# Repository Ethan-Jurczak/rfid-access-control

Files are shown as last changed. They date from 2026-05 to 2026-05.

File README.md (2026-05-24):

# rfid-access-control
stm32 based RFID system.
# Specs
- Runs off a STM32f411ret arm microcontroller with a EM4095 for the RFID demodulation and writing modulation.
- Includes a USB-C receptacle for both power and data transfer to the STM32
- Includes a 4 pin connecter for programing with a STlink
- 520 uH coil connected in series accross 4 layers to minimize space while maximising Q
# Schematics
- [RFID-Read-Write-Schematic.pdf](https://github.com/user-attachments/files/28185533/RFID-Read-Write-Schematic.pdf)
RFID-Read-Write-Front
RFID-Read-Write-Back

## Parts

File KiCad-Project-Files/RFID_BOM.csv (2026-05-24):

Reference | Qty | Value | DNP | Exclude from BOM | Exclude from Board | Footprint | Datasheet
AccessLed1,AccessLed2 | 2 | LED |  |  |  | LED_SMD:LED_0603_1608Metric
C1,C2 | 2 | 33 pF |  |  |  | Capacitor_SMD:C_0402_1005Metric
C3,C5,C7,C9,C10,C11,C12,C14,C17,CDEC1 | 10 | 100nF |  |  |  | Capacitor_SMD:C_0402_1005Metric
C4 | 1 | 150nF |  |  |  | Capacitor_SMD:C_0402_1005Metric
C6 | 1 | 1 uF |  |  |  | Capacitor_SMD:C_0402_1005Metric
C8 | 1 | 4.7uF |  |  |  | Capacitor_SMD:C_0603_1608Metric
C13 | 1 | 1uF |  |  |  | Capacitor_SMD:C_0402_1005Metric
C16,C18 | 2 | 10 uF |  |  |  | Capacitor_SMD:C_0805_2012Metric
CDC1,CFCAP1 | 2 | 10nF |  |  |  | Capacitor_SMD:C_0603_1608Metric
CDV1 | 1 | 56pF |  |  |  | Capacitor_SMD:C_0805_2012Metric
CDV2 | 1 | 1.5nF |  |  |  | Capacitor_SMD:C_0805_2012Metric
CRES1 | 1 | 3nF |  |  |  | Capacitor_SMD:C_0603_1608Metric
CTUNE1 | 1 | ?pF |  |  |  | Capacitor_SMD:C_0402_1005Metric
D1 | 1 | PTVS5V0Z1USK |  |  |  | Diode_SMD:Nexperia_DSN1608-2_1.6x0.8mm | https://assets.nexperia.com/documents/data-sheet/PTVS5V0Z1USK.pdf
EM1 | 1 |  |  |  |  | EM4095:SO16
F1 | 1 | MF-MSMF050-2 |  |  |  | Fuse:Fuse_1812_4532Metric
FB1 | 1 | 600 Ohm @ 100mHz |  |  |  | Inductor_SMD:L_0805_2012Metric
J1 | 1 | Conn_01x04_Pin |  |  |  | Connector_JST:JST_EH_B4B-EH-A_1x04_P2.50mm_Vertical
J2 | 1 | USB_C_Receptacle |  |  |  | EM4095:SAMESKY_UJ20-C-H-G-SMT-1-P16-TR | https://www.usb.org/sites/default/files/documents/usb_type-c.zip
LA1 | 1 | 520uH
Q1 | 1 | 2N7002 |  |  |  | Package_TO_SOT_SMD:SOT-23 | https://www.onsemi.com/pub/Collateral/NDS7002A-D.PDF
R1 | 1 | 100 Ohm |  |  |  | Resistor_SMD:R_0402_1005Metric
R2,R8 | 2 | 10k Ohm |  |  |  | Resistor_SMD:R_0603_1608Metric
R3,R4 | 2 | 22 Ohm |  |  |  | Resistor_SMD:R_0402_1005Metric
R5,R6 | 2 | 5.1k Ohm |  |  |  | Resistor_SMD:R_0402_1005Metric
R9 | 1 | 100 Ohm |  |  |  | Resistor_SMD:R_0603_1608Metric
RSER1 | 1 | 33Ohm |  |  |  | Resistor_SMD:R_0402_1005Metric
R_FB1 | 1 | 1M Ohm |  |  |  | Resistor_SMD:R_0402_1005Metric
Status1 | 1 | LED |  |  |  | LED_SMD:LED_0805_2012Metric
SW1,SW2 | 2 | SW_Push |  |  |  | Button_Switch_SMD:SW_Tactile_SPST_NO_Straight_CK_PTS636Sx25SMTRLFS
U1 | 1 | STM32F411RETx |  |  |  | Package_QFP:LQFP-64_10x10mm_P0.5mm | https://www.st.com/resource/en/datasheet/stm32f411re.pdf
U2 | 1 | USBLC6 |  |  |  | Package_TO_SOT_SMD:SOT-23-6 | https://www.st.com/resource/en/datasheet/usblc6-2.pdf
VR1 | 1 | LM1117MPX-3.3_NOPB |  |  |  | Package_TO_SOT_SMD:SOT-223-3_TabPin2
Y1 | 1 | ECS-80-20-5PXDU-TR |  |  |  | EM4095:XTAL_ECS-80-20-5PXDU-TR

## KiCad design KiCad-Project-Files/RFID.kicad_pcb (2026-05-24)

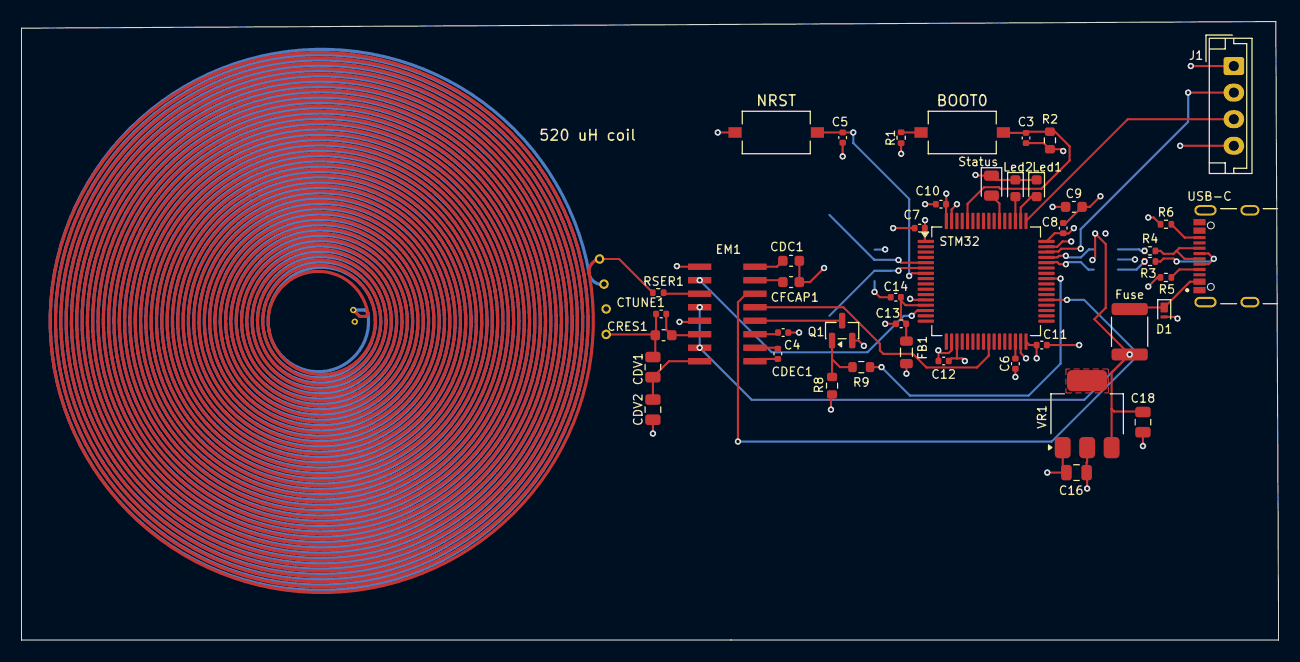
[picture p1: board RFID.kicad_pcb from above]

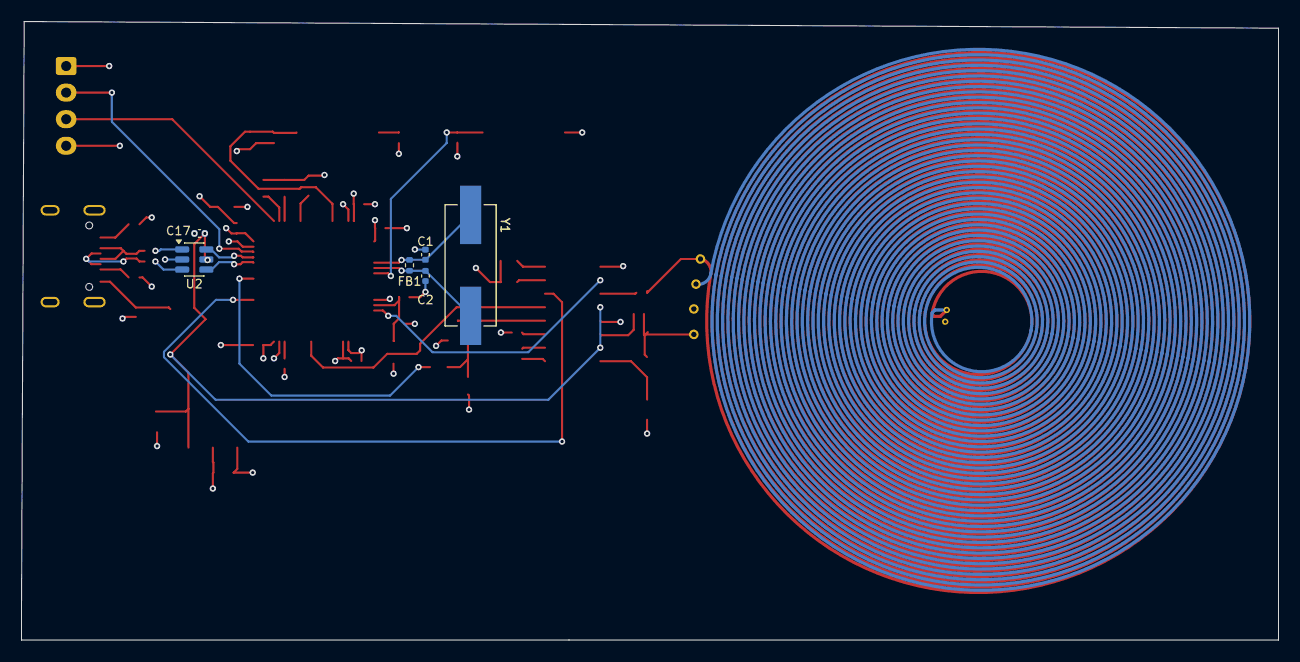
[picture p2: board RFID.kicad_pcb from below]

Board: 4 copper layers, 118.2 x 58.2 mm, 51 parts (6 on the bottom side), 36 nets.

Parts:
520 uH coil: 520 uH coil
BOOT0: SW_Push; SW_Tactile_SPST_NO_Straight_CK_PTS636Sx25SMTRLFS
C1, C2: 33 pF; C_0402_1005Metric
C3, C5, C7, C9, C10, C11, C12, C14, C17: 100nF; C_0402_1005Metric
C4: 150nF; C_0402_1005Metric
C6: 1 uF; C_0402_1005Metric
C8: 4.7uF; C_0603_1608Metric
C13: 1uF; C_0402_1005Metric
C16, C18: 10 uF; C_0805_2012Metric
CDC1: 10nF; C_0603_1608Metric
CDEC1: 100nF; C_0402_1005Metric
CDV1: 56pF; C_0805_2012Metric
CDV2: 1.5nF; C_0805_2012Metric
CFCAP1: 10nF; C_0603_1608Metric
CRES1: 3nF; C_0603_1608Metric
CTUNE1: ?pF; C_0402_1005Metric
D1: PTVS5V0Z1USK; Nexperia_DSN1608-2_1.6x0.8mm
EM1: SO16
FB1: 600 Ohm @ 100mHz; L_0805_2012Metric
FB1#2: 1M Ohm; R_0402_1005Metric
Fuse: MF-MSMF050-2; Fuse_1812_4532Metric
J1: Conn_01x04_Pin; JST_EH_B4B-EH-A_1x04_P2.50mm_Vertical
Led1, Led2: LED; LED_0603_1608Metric
NRST: SW_Push; SW_Tactile_SPST_NO_Straight_CK_PTS636Sx25SMTRLFS
Q1: 2N7002; SOT-23
R1: 100 Ohm; R_0402_1005Metric
R2, R8: 10k Ohm; R_0603_1608Metric
R3, R4: 22 Ohm; R_0402_1005Metric
R5, R6: 5.1k Ohm; R_0402_1005Metric
R9: 100 Ohm; R_0603_1608Metric
RSER1: 33Ohm; R_0402_1005Metric
STM32: STM32F411RETx; LQFP-64_10x10mm_P0.5mm
Status: LED; LED_0805_2012Metric
U2: USBLC6; SOT-23-6
USB-C: USB_C_Receptacle; SAMESKY_UJ20-C-H-G-SMT-1-P16-TR
VR1: LM1117MPX-3.3_NOPB; SOT-223-3_TabPin2
Y1: ECS-80-20-5PXDU-TR; XTAL_ECS-80-20-5PXDU-TR

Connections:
+3.3V: C7.2, C8.2, C9.2, C10.2, C11.2, C12.2, C16.1, FB1.2, J1.1, R1.1, STM32.1 (VBAT), STM32.19 (VDD), STM32.32 (VDD), STM32.48 (VDD), STM32.64 (VDD), VR1.2 (VOUT_2)
+5V: C17.1, C18.1, EM1.4 (DVDD), EM1.7 (VDD), Fuse.1, U2.5 (VBUS), VR1.3 (VIN)
/BOOT0: BOOT0.2, C3.1, R2.1, STM32.60 (BOOT0)
/D+: R4.1, R4.2, STM32.45 (PA12), U2.1 (I/O1), U2.6 (I/O1), USB-C.A6 (D+), USB-C.B6 (D+)
/D-: R3.1, R3.2, STM32.44 (PA11), U2.3 (I/O2), U2.4 (I/O2), USB-C.A7 (D-), USB-C.B7 (D-)
/NRST: C5.1, NRST.2, STM32.7 (NRST)
/OSC_IN: C1.2, FB1#2.1, STM32.5 (PH0), Y1.1
/OSC_OUT: C2.1, FB1#2.2, STM32.6 (PH1), Y1.2
/SWCLK: J1.3, STM32.49 (PA14)
/SWDIO: J1.2, STM32.46 (PA13)
/VBUS: D1.1 (K), Fuse.2, USB-C.A4_B9
/VDDA: C13.1, C14.1, FB1.1, STM32.13 (VDDA)
GND: C1.1, C2.2, C3.2, C4.2, C5.2, C6.2, C7.1, C8.1, C9.1, C10.1, C11.1, C12.1, C13.2, C14.2, C16.2, C17.2, C18.2, CDC1.2, CDV2.2, CFCAP1.2, D1.2 (A), EM1.1 (VSS), EM1.5 (DVSS), J1.4, Led1.1 (K), Led2.1 (K), NRST.1, Q1.2 (S), R2.2, R5.1, R6.1, R8.1, STM32.12 (VSSA), STM32.18 (VSS), STM32.31 (VSS), STM32.47 (VSS), STM32.63 (VSS), Status.1 (K), U2.2 (GND), VR1.1 (GND)
unnamed: Led1.2 (A), STM32.50 (PA15)
unnamed: Led2.2 (A), STM32.51 (PC10)
unnamed: CDV1.1, CRES1.1, CTUNE1.1
unnamed: C4.1, EM1.11 (AGND)
unnamed: EM1.3 (ANT1), RSER1.2
unnamed: CRES1.2, CTUNE1.2, EM1.6 (ANT2)
unnamed: CDEC1.1, EM1.10 (CDEC_In)
unnamed: CDEC1.2, EM1.9 (CDEC_Out)
unnamed: CDC1.1, EM1.16 (DC2)
unnamed: CDV1.2, CDV2.1, EM1.8 (DMOD-IN)
unnamed: EM1.13 (DMOD_Out), STM32.25 (PC5)
unnamed: CFCAP1.1, EM1.15 (FCAP)
unnamed: EM1.12 (MOD), Q1.3 (D)
unnamed: EM1.2 (RDY/CLK), STM32.14 (PA0)
unnamed: EM1.14 (SHD), STM32.37 (PC6)
unnamed: R5.2, USB-C.A5 (CC1)
unnamed: R6.2, USB-C.B5 (CC2)
unnamed: 520 uH coil.1, RSER1.1
unnamed: Q1.1 (G), R8.2, R9.2
unnamed: BOOT0.1, R1.2
unnamed: STM32.54 (PD2), Status.2 (A)
unnamed: R9.1, STM32.41 (PA8)
unnamed: C6.1, STM32.30 (VCAP1)

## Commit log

2026-05-24 Create KiCad-Project-Files folder
2026-05-24 Add All KiCad project files
    current as of 5/23/26
    [RFID.kicad_pcb, RFID.kicad_sch, RFID_BOM.csv]
